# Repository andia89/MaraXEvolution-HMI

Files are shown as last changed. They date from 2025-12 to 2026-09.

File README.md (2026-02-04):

# MaraX Evolution - HMI

[](https://github.com/user-attachments/assets/6cd800d1-d086-4739-b1a8-fa24eb85fd67)

This repository contains the hardware designs, 3D printed parts, and firmware for the **MaraX Evolution Human-Machine Interface (HMI)**.

Designed to replace the standard LEDs and switches of the Lelit Mara X, this unit provides a rich touchscreen interface, real-time extraction charting, and a physical rotary encoder for tactile control. It communicates wirelessly with the [Main Controller](https://github.com/andia89/maraxevolution) via ESP-NOW, ensuring a low-latency, wire-free installation.

## Features

### Visual Interface

* **Real-Time Charting:** Live visualization of **Pressure (bar)** and **Flow Rate (g/s)** during the shot.

* **Live Telemetry:** Monitors Boiler Temp, HX Temp, Shot Timer, and Weight.

* **System Status:** Clear indicators for Heating, Ready, Steam Boost, and Error states.

### Control & Profiling

* **Profile Editor:** Built-in **Web Server** to create, edit, and save complex pressure/flow profiles graphically from your phone or PC.

* **Profile Management:** Store up to **32 custom profiles** on the device.

* **Manual Control:** "Fly-by-wire" manual mode using the rotary encoder to control pump pressure/flow in real-time.

* **Configuration:** Adjust PID targets, brew temperatures, and steam settings directly from the screen.

### Maintenance & Tools

* **Scale Calibration:** On-screen wizard to tare and calibrate the [MaraX Evolution Scale](https://github.com/andia89/maraxevolution-scale).

* **Cleaning Assistant:** Guided backflush/cleaning cycles with on-screen instructions.

* **Auto-Pairing:** Seamlessly pairs with the Main Controller via ESP-NOW protocol.

## Repository Structure

* `HMI/`: Nextion Editor source files (`.hmi`), compiled binaries (`.tft`), and asset generation scripts.

* `firmware/`: PlatformIO project for the HMI controller (ESP32).

* `hardware/`: STL files for the 3D printed housing and mounting brackets.

## Hardware Overview

The HMI consists of:

1. **Microcontroller:** Arduino Nano ESP32 (handling Logic, WiFi, Web Server).

2. **Display:** Nextion Edge Series (NX4848E028-011C).

3. **Input:** Rotary Encoder and Push Button (for precise adjustments).

4. **Housing:** Custom 3D printed enclosure.

## [User Guide](USERGUIDE.md)

## [Parts list](PARTS.md)

## [Assembly Instructions](ASSEMBLY.md)

## Firmware Installation

The firmware is built using **PlatformIO**.

1. Install [VSCode](https://code.visualstudio.com/) and the [PlatformIO extension](https://platformio.org/).
2. Open the `firmware` directory in PlatformIO.

### 1. Initial Flash (USB)
For the first installation, you must connect the ESP32 directly to your computer.
1. Connect the ESP32 via USB.
2. Select the default environment (`env:hmi`) in PlatformIO.
3. Click the **Upload** button (Right Arrow icon).

### 2. Subsequent Updates (OTA)
Once the HMI is installed in the machine and connected to your WiFi, you can update it wirelessly.
1. Ensure your computer and the HMI are on the same WiFi network.
2. Select the ota environment (`env:hmi-ota`) in PlatformIO.
3. Click **Upload**. PlatformIO will detect the network port and flash the device over the air.

## Firmware Configuration

The HMI firmware is designed to run on an **Arduino Nano ESP32**.

1. **WiFi Setup:** On first boot, the HMI will create a WiFi Access Point (AP) named `esp32-arduino-screen-Setup`. Connect to it to configure your home WiFi.

2. **Web Interface:** Once connected, access the Profile Editor at `http://esp32-arduino-screen.local` (or the device IP).

3. **Pairing:** The HMI automatically broadcasts an ESP-NOW pairing request. Ensure the Main Controller is powered on; they will find each other automatically.

## Licensing

This project is dual-licensed to protect the work while allowing for personal study and modification.

* **Firmware:** The source code located in the `/firmware` directory is licensed under the **PolyForm Noncommercial License 1.0.0**. You may modify and use it for personal projects, but **commercial use is prohibited**.

  * *Third-Party Libraries included:* Modified versions of [Nextion_X2](https://github.com/sstaub/NextionX2) (MIT).

* **Hardware:** The hardware designs, schematics, and 3D models located in the `/HMI` and `/hardware` directories are licensed under the **Creative Commons Attribution-NonCommercial 4.0 International (CC BY-NC 4.0)** license.

Please see the [LICENSE](LICENSE) file for the full legal text.

*Part of the [MaraX Evolution Ecosystem](https://github.com/andia89/maraxevolution).*

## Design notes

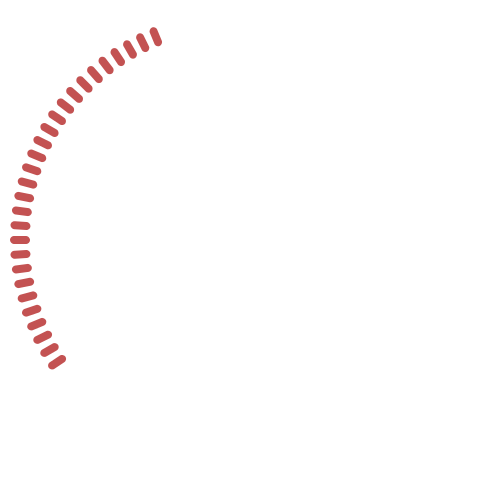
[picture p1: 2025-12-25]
HMI/pictures/boiler_28.png

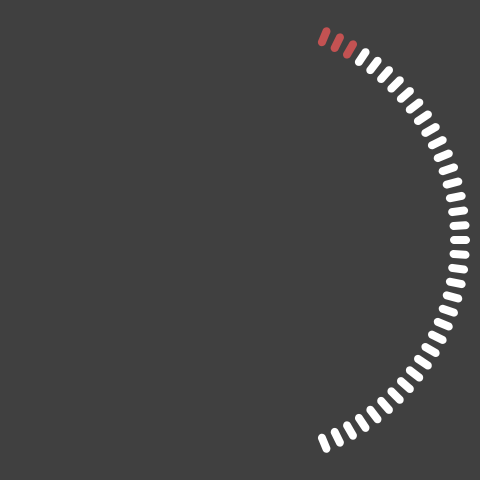
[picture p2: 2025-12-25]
HMI/pictures/brew_3.png

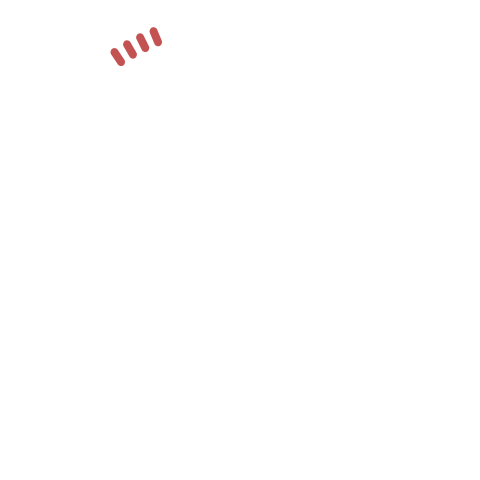
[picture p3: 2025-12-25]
HMI/pictures/boiler_4.png

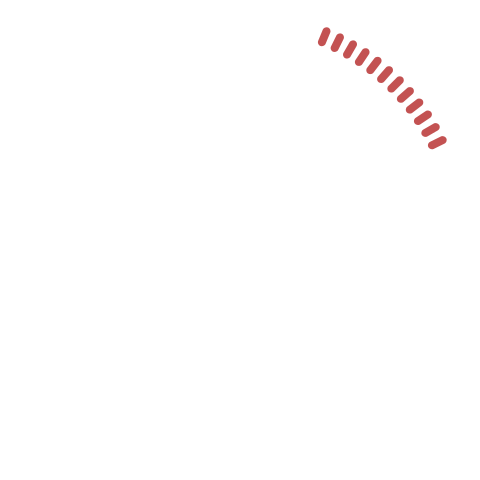
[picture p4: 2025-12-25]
HMI/pictures/brew_12.png

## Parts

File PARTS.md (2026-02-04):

# MaraX Evolution HMI - Parts List

This document lists all the components required to build the MaraX Evolution Human-Machine Interface (HMI).

## Electronics & Display

| Component | Description | Quantity | Notes |
| :--- | :--- | :---: | :--- |
| **Microcontroller** | Arduino Nano ESP32 | 1 | Must include headers. Installs into the bottom section of the housing. |
| **Display** | Nextion [NX4848E028-011C](https://nextion.tech/) | 1 | 2.8" Edge Series HMI Touchscreen. |
| **Rotary Encoder** | Bourns PEC16-4125F-N0012 | 1 | Used for manual pressure control and menu navigation. |
| **Tactile Switch** | 506-FSM5JH | 1 | External push button for the encoder assembly (if not integrated). |
| **Cabling** | Dupont Cables (F-F / M-F) | Set | For connecting the Arduino to the Display and Encoder. |
| **Storage** | Micro SD Card | 1 | Required only for flashing the firmware onto the Nextion screen. |

## Housing & Hardware

| Component | Description | Quantity | Notes |
| :--- | :--- | :---: | :--- |
| **3D Printed Parts** | Custom Enclosure | 1 Set | STL files are located in `HMI/3DParts/`. I printed mine in PLA and was quite happy with it|
| **Threaded Inserts** | [M3 Threaded Inserts](https://www.ruthex.de/en/products/ruthex-gewindeeinsatz-m3-100-stuck-rx-m3x5-7-messing-gewindebuchsen) | 10 | Standard heat-set inserts (e.g., Ruthex M3x5.7). Any should do|
| **Teflon Plunger** | [M3 Teflon Plunger](https://de.aliexpress.com/item/1005009562484175.html) | 3 | **Critical:** Get the longest version available. Used to provide smooth rotation feel. |
| **Friction Tape** | [Teflon Tape (10mm)](https://de.aliexpress.com/item/1005005280321356.html) | 1 Roll | Applied between moving 3D printed parts to remove friction. |
| **Fasteners** | M3 Machine Screws | Assorted | A selection of lengths (6mm - 12mm) for assembling the case. |

---

*Note: Links provided are for reference and may change over time.*

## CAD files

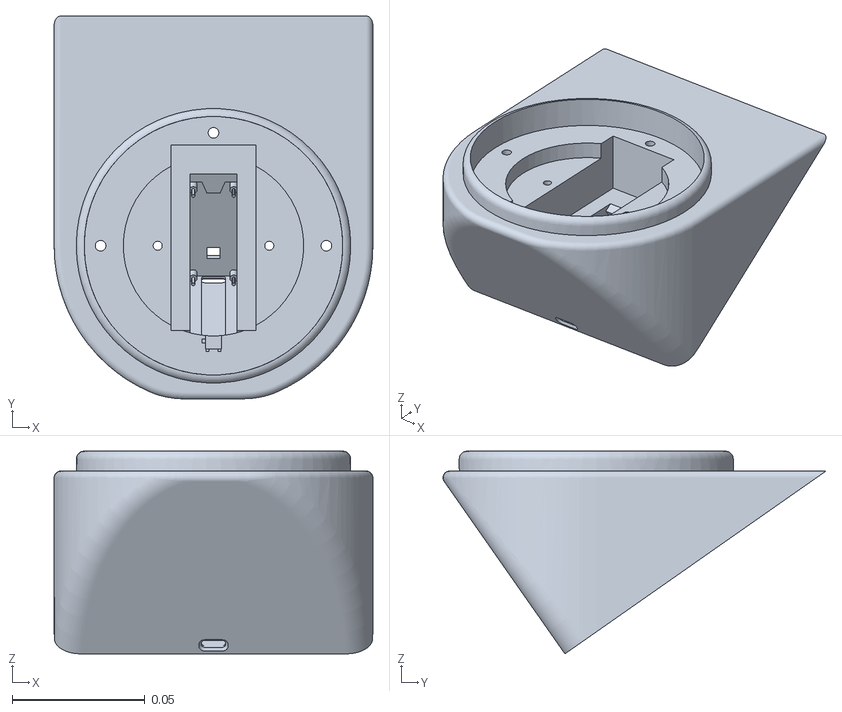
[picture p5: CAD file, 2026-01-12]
HMI/3DParts/Stand.stl
0.12 x 0.144 x 0.0763

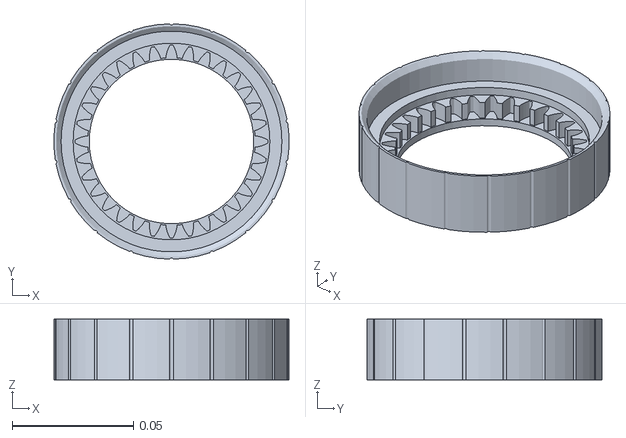
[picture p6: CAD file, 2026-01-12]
HMI/3DParts/Outer Housing.stl
0.0968 x 0.0969 x 0.025

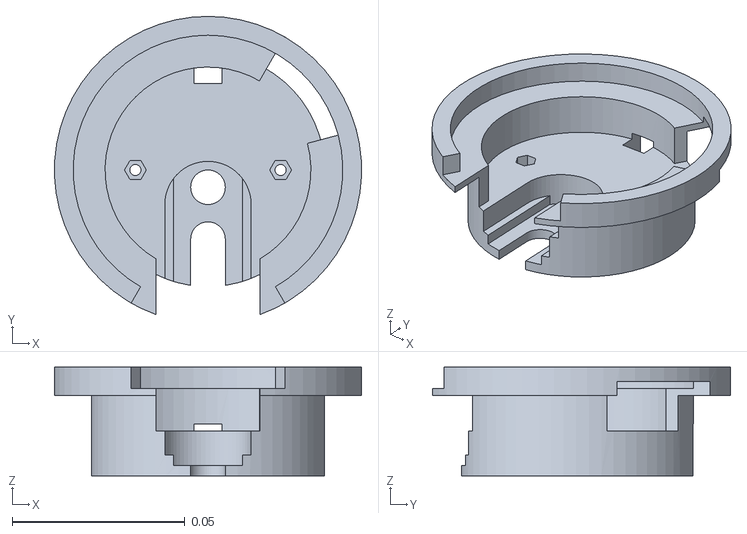
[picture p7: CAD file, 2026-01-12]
HMI/3DParts/Housing.stl
0.0888 x 0.0863 x 0.0314

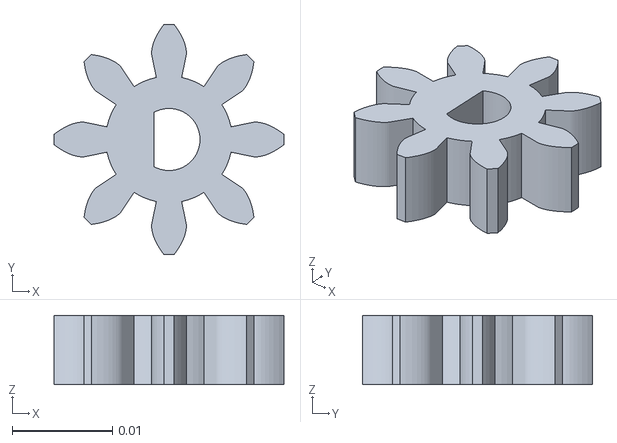
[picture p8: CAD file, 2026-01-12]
HMI/3DParts/Inner gear.stl
0.023 x 0.023 x 0.0069

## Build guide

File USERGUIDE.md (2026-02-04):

# **MaraX Evolution HMI \- User Guide**

This guide explains how to use the Nextion Touchscreen Interface and the Rotary Encoder to control your MaraX Evolution machine.

## **1\. First-Time Setup**

### **WiFi Configuration**

When powered on for the first time (or if it cannot connect to WiFi), the HMI creates a Hotspot.

1. Connect your phone or laptop to the WiFi network named: **esp32-arduino-screen-Setup**.  
2. A captive portal should open automatically (or visit 192.168.4.1).  
3. Select your home WiFi network and enter the password.  
4. The device will reboot and connect to your local network.

### **Pairing with Main Controller**

The HMI communicates with the machine via **ESP-NOW** (a fast, direct wireless protocol).

1. Ensure the **Main Controller** (inside the machine) is powered on.  
2. Power on the **HMI**.  
3. They will automatically find each other and pair within 10 seconds. You will see live temperature data appear once paired.

## **2\. Dashboard (Home Screen)**

This is the main view while brewing.

* **Live Chart:** Visualizes the shot in real-time.  
  * **Red Line:** Pressure (0-15 bar).  
  * **Blue Line:** Flow Rate (0-5 g/s) \[Requires Scale\].  
  * **White Line:** Target Profile.  
* **Data Fields:**  
  * **Timer:** Starts automatically when the pump engages.  
  * **Weight:** Live gram reading from the drip tray scale.  
  * **Temperatures:** Boiler (Steam) and Heat Exchanger (Brew) temps.  
* **Tare Button:** Zeros the scale manually \[Requires Scale\].

## **3\. Brewing Settings (Page 1\)**

Access this page to change machine parameters.

* **Brew Temperature:**  
  * Use the **Slider** on the touchscreen OR turn the **Rotary Encoder** to adjust the target brew temperature (e.g., 93.0°C).  
* **Brew Mode:**  
  * **Coffee Priority:** Keeps the heat exchanger at the perfect brew temp. Steam might be weaker.  
  * **Steam Priority:** Keeps the boiler hot for powerful steam. Brew temp may fluctuate more.  
* **Steam Boost:**  
  * When enabled, the machine aggressively heats the boiler immediately after a shot is finished to recover steam pressure quickly.

## **4\. Pressure & Flow Profiling (Page 2\)**

This menu controls how the pump operates during a shot.

### **Modes**

1. **Manual:** The machine behaves like a standard espresso machine (full pump power).  
2. **Flat:** The pump targets a specific constant value (e.g., maintain exactly 9.0 bar or 2.0 g/s).  
   * Select "Flat" and turn the encoder to set the target value.  
3. **Profile:** The machine follows a saved pre-programmed curve.

### **Profile Configuration**

* **Source:** Choose what the pump controls.  
  * **Pressure:** Standard profiling (e.g., pre-infusion at 2 bar, ramp to 9 bar).  
  * **Flow:** \[Requires Scale\] The pump adjusts to maintain a specific flow rate (e.g., 2.5 g/s) regardless of puck resistance.  
* **Target:** Choose when to advance to the next step.  
  * **Time:** Steps change after X seconds.  
  * **Weight:** Steps change after X grams are in the cup.

### **Selecting & Editing Profiles**

* **Select:** Turn the Rotary Encoder to cycle through saved profiles (displayed at the bottom).  
* **Edit (On-Screen):** Tap the table cells to select them, then turn the Encoder to adjust values (Target / Duration).  
* **Edit (Web Interface):** See Section 6 below.

## **5\. Maintenance (Page 3\)**

### **Scale Calibration**

1. Navigate to **System Settings**.  
2. Tap **Calibrate Scale**.  
3. **Step 1:** Ensure the scale is empty. Tap "Next" or the Encoder button to Tare.  
4. **Step 2:** Place a known weight on the scale.  
5. **Step 3:** Use the **Rotary Encoder** to adjust the displayed "Reference Weight" until it matches your known weight (e.g., 100.0g).  
6. Press the Encoder button to save.

### **Cleaning Cycle**

Automated backflush routine.

1. Insert a blind basket and detergent.  
2. Tap **Cleaning Cycle**.  
3. Follow the on-screen prompts:  
   * "Pull Lever" (Starts Pump)  
   * "Lower Lever" (When buzzing/pausing)  
   * Repeat 5x with detergent, 5x with water.

### **MQTT Configuration**

If connected to WiFi, tapping **System Settings** displays an IP address. Enter this IP in a web browser to configure your MQTT Broker settings for Home Assistant integration. This sets the MQTT settings for the main controller.

## **6\. Web Profile Editor**

The HMI hosts a built-in website for easier profile creation.

1. Ensure the HMI is connected to your WiFi.  
2. On a computer or phone connected to the same WiFi, open a browser.  
3. Go to: **http://esp32-arduino-screen.local**  
4. **Features:**  
   * Visual Graph Editor: Drag and drop points to create profiles.  
   * Save/Load: Save profiles to the HMI's memory slots (up to 32).  
   * Import/Export: Share profiles as JSON files.  
   * Live Sync: Changes made on the web update the screen instantly.

## **7\. Troubleshooting**

* **"System Message: Timeout"**: The main controller didn't respond. Ensure the machine is on. If the issue persists, reboot the HMI.  
* **No Chart Data:** Check if the scale is connected properly to the main controller.  
* **WiFi Issues:** If you change your WiFi password, the device will eventually reset to Hotspot mode (esp32-arduino-screen-Setup) so you can re-configure it.

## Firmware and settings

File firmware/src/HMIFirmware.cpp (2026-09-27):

// =================================================================
// --- LIBRARIES ---
// =================================================================
#include <WiFi.h>
#include "NextionTftUpdate.h"
#include <freertos/FreeRTOS.h>
#include <freertos/queue.h>
#include <ESP32RotaryEncoder.h>
#include "NextionX2.h"
#include <ArduinoOTA.h>
#include <ArduinoJson.h>
#include <esp_now.h>
#include <WebServer.h>
#include <DNSServer.h>
#include <WiFiManager.h>
#include <ESPmDNS.h>
#include <esp_pm.h>
#include <esp_wifi.h>
#include <esp_wifi_types.h>

// =================================================================
// --- CONFIGURATION & DEFINES ---
// =================================================================
bool SIMULATION_MODE = false;
const bool OFFLINE_MODE = false;
const float TEMP_SETPOINT_SCALE = 10.0f;
const int SHOT_RETENTION_TIME_MS = 10000;
const int CHART_RETENTION_TIME_MS = 3000;

// =================================================================
// --- HARDWARE PIN DEFINITIONS ---
// =================================================================
const uint8_t BUTTON_PIN = D5;
const uint8_t ENCODER_PIN_A = D4;
const uint8_t ENCODER_PIN_B = D3;
const uint8_t SERIAL_RX = D9;
const uint8_t SERIAL_TX = D8;

// =================================================================
// --- NETWORK CONFIGURATION ---
// =================================================================
// --- Wi-Fi Credentials ---
const char *WIFI_SSID = "";
const char *WIFI_PASSWORD = "";

// --- OTA (Over-the-Air Updates) ---
const char *OTA_HOSTNAME = "esp32-arduino-screen";
const char *OTA_PASSWORD = "1234";

// Nextion TFT updates: Python connects here even when the normal portal is off.
// Set a separate shared token if desired; the default reuses your OTA password.
const char *TFT_UPDATE_TOKEN = OTA_PASSWORD;
const uint16_t TFT_UPDATE_PORT = 8080;
NextionTftUpdate tftUpdater(Serial1, TFT_UPDATE_TOKEN, TFT_UPDATE_PORT);

// Received bools for settings
bool brewModeReceived = false;
bool steamBoostReceived = false; // Flag to know if false is real or default
bool flatValueReceived = false;
bool profilingSourceReceived = false;
bool profilingTargetReceived = false;
bool profilingModeReceived = false;
bool currentProfileReceived = false;
bool tempsetReceived = false;
bool setupFinished = false;

// --- Temporary Buffers for Web Forms ---
char form_mqtt_server[40] = ""; // Default values for the form
char form_mqtt_port_str[6] = "1883";
char form_mqtt_user[33] = "";
char form_mqtt_password[33] = "";

// --- WebServer for Connected Config ---
WebServer server(80);
bool portalRunning = false;
bool mqttSettingsPending = false;

// --- MQTT Topics ---
const char *mqtt_topic_state = "state";
const char *mqtt_topic_boiler_temp = "boiler_temp";
const char *mqtt_topic_hx_temp = "hx_temp";
const char *mqtt_topic_pressure = "pressure";
const char *mqtt_topic_heater = "heater";
const char *mqtt_topic_pump = "pump";
const char *mqtt_topic_brew_mode = "brew_mode";
const char *mqtt_topic_lever = "lever";
const char *mqtt_topic_setpoint = "tempsetbrew";
const char *mqtt_topic_weight = "weight";
const char *mqtt_topic_flow_rate = "flow_rate";
const char *mqtt_topic_steam_boost_status = "steam_boost";
const char *mqtt_topic_set_profiling_mode = "profiling_mode";
const char *mqtt_topic_set_profiling_source = "profiling_source";
const char *mqtt_topic_set_profiling_target = "profiling_target";
const char *mqtt_topic_set_profiling_flat = "profiling_flat_value";
const char *mqtt_topic_mqtt_server = "mqtt_server";
const char *mqtt_topic_mqtt_port = "mqtt_port";
const char *mqtt_topic_mqtt_user = "mqtt_user";
const char *mqtt_topic_mqtt_pass = "mqtt_pass";
const char *mqtt_topic_import_profile = "profile_data";
const char *mqtt_topic_active_profile_id = "active_profile_id";
// =================================================================
// --- SYSTEM & LIBRARY OBJECTS ---
// =================================================================
// --- Hardware ---
RotaryEncoder rotaryEncoder(ENCODER_PIN_A, ENCODER_PIN_B, BUTTON_PIN);
const long ROTARY_MIN_BOUND = 0;
const long ROTARY_MAX_BOUND = 12;

// --- Nextion Display Communication Port ---
// This gate lets the rest of the HMI resume after a failed flash without
// accidentally feeding ordinary UI commands into an unfinished TFT transfer.
// NextionX2 accepts a Stream-compatible object; the uploader uses raw Serial1.
class HmiDisplaySerial : public Stream
{
public:
  bool enabled = true;
  void begin(uint32_t baud) { Serial1.begin(baud, SERIAL_8N1, SERIAL_RX, SERIAL_TX); }
  int available() override { return enabled ? Serial1.available() : 0; }
  int read() override { return enabled ? Serial1.read() : -1; }
  int peek() override { return enabled ? Serial1.peek() : -1; }
  void flush() override
  {
    if (enabled)
      Serial1.flush(true);
  }
  size_t write(uint8_t value) override { return enabled ? Serial1.write(value) : 1; }
  size_t write(const uint8_t *data, size_t size) override
  {
    return enabled ? Serial1.write(data, size) : size;
  }
  using Print::write;
};
HmiDisplaySerial hmiDisplaySerial;
NextionComPort nextion;

// --- ESP-NOW Auto-Pairing ---
#define PAIR_REQUEST 1
#define PAIR_RESPONSE 2
char espNowMessageBuffer[250] = "";
uint8_t broadcastAddress[] = {0xFF, 0xFF, 0xFF, 0xFF, 0xFF, 0xFF};
uint8_t mainControllerMac[6] = {0x00, 0x00, 0x00, 0x00, 0x00, 0x00};
int myChannel = 0;
esp_now_peer_info_t peerInfo;
volatile bool espNowBusy = false;

// Define a structure for ESP-NOW messages
typedef struct struct_message
{
  char payload[250];
} struct_message;
typedef struct struct_pairing
{
  uint8_t id;
  uint8_t macAddr[6];
  uint8_t channel;
  char identifier[10];
} struct_pairing;
const char *espIdentifier = "espresso";

// The Wi-Fi callback must never use NextionX2 or touch Serial1. Queue packets
// for loop(), which owns all display traffic, including TFT upload traffic.
struct HmiRxPacket
{
  uint8_t mac[6];
  uint16_t len;
  uint8_t data[sizeof(struct_message)];
};
QueueHandle_t hmiRxQueue = nullptr;

struct_message myData;
struct_pairing pairingData;
// =================================================================
// --- GLOBAL STATE & CONTROL VARIABLES ---
// =================================================================
// --- Machine State (from MQTT) ---
float boilerTemp = 0.0f;
float brewTempSetPoint = 0.0f;
float hxTemp = 0.0f;
float pressure = 0.0f;
float weight = 0.0f;
bool isHeaterOn = false;
bool brewLeverLifted = false;
volatile bool pumpIsOn = false;
char machineState[64] = "";
char profilingMode[20] = "";
char profilingSource[20] = "pressure";
char profilingTarget[20] = "time";
unsigned long calibrationRequestTime = 0;
const long CALIBRATION_REQUEST_TIMEOUT_MS = 10000; // 10-second timeout
int calibrationStep = 0;                           // 0=Off, 1=Waiting for Tare, 2=Waiting for Weigh
unsigned long systemMessageClearTime = 0;
bool cleaningCycleActive = false;
unsigned long cleaningRequestTime = 0;
const long CLEANING_REQUEST_TIMEOUT_MS = 10000;
int cleaningCycleCount = 0;
float referenceWeight;
unsigned long chartStopTime = 0;

// --- ESP Now paring variables ---
unsigned long lastPairingRequestTime = 0;
const long PAIRING_REQUEST_INTERVAL_MS = 10000;
bool isPaired = false;
unsigned long lastControllerMessageTime = 0;
const long CONTROLLER_TIMEOUT_MS = 10000;

// --- Display & UI State ---
volatile int currentPage = 0;
int lastPageForSelection = 0;
volatile int currentSelectionIndex = 0;
volatile bool isItemSelected = false;

// --- Input Handling (Encoder & Button) ---
volatile long lastEncoderValue = 0;
volatile long encoderTicks = 0;
volatile bool buttonPressed = false;
portMUX_TYPE encoderMux = portMUX_INITIALIZER_UNLOCKED;
unsigned long lastEncoderActivityTime = 0;
int pendingSettingIndex = -1;
const int SETTING_ID_FLAT_VALUE = 100;
const int SETTING_ID_PROFILING_VALUE = 101;
const long PUBLISH_TIMEOUT = 1000;

// --- Shot & Flow Tracking ---
int shotTime = 0;
unsigned long shotStartTimeMillis = 0;
const int SHOT_START_THRESHOLD_S = 1;
bool shotIsActive = false;
const int MAX_SHOT_TIME_S = 50;

// --- Flow Rate Calculation ---
float flowRate = 0.0f;

// --- Raw Debug Data (for plotdebug mode) ---
float rawWeight = 0.0f;
float filteredWeight = 0.0f;
float filteredFlow = 0.0f;
unsigned long lastDebugDataTime = 0;
const long DEBUG_PLOT_TIMEOUT_MS = 2000;

// --- New scales for the debug plot mode ---
const float DEBUG_WEIGHT_MAX = 200.0;
const float DEBUG_WEIGHT_MIN = 0.0;
const float DEBUG_FLOW_MAX = 10.0;
const float DEBUG_FLOW_MIN = 0.0;

// --- Value Caching for Display Optimization ---
int lastShotTime_sent = -1;
float lastHxTemp_sent = -1.0f;
float lastBoilerTemp_sent = -1.0f;
float lastPressure_sent = -1.0f;
float lastTempSetpoint_sent = 0.0f;
float lastWeight_sent = -1.0f;
char lastMachineState_sent[64] = "";

// --- Settings Request Timer ---
unsigned long lastSettingsRequestTime = 0;
const long SETTINGS_REQUEST_INTERVAL_MS = 10000;

struct ProfileStep
{
  float target;
  float control;
};

struct EspressoProfile
{
  char name[65];
  bool isStepped;
  bool isTargetWeight;  // false = time, true = weight
  bool isSourceFlow;    // false = pressure, true = flow
  int8_t nextProfileId; // Profile ID to run next (-1 for none)
  int numSteps;
  ProfileStep steps[128];
};

EspressoProfile *currentProfile = nullptr;
#define MAX_PROFILES 16
EspressoProfile profiles[MAX_PROFILES];
int currentProfileIndex = 0;

EspressoProfile *executingProfile = nullptr;
unsigned long profileStartTime = 0;
float profileStartWeight = 0.0f;
int currentProfileStepIndex = 0;
float currentStepStartX = 0.0f;
float prevStepTargetY = 0.0f;

bool currentProfileDirty = false;
unsigned long profileIndexSettleTime = 0;
bool profileIndexPendingSave = false;
const unsigned long PROFILE_SAVE_DELAY_MS = 3000;

// Webserver
bool profileWebserverRunning = false;
extern const uint8_t profile_editor_start[] asm("_binary_src_www_profile_html_start");
extern const uint8_t profile_editor_end[] asm("_binary_src_www_profile_html_end");

// =================================================================
// --- NEXTION COMPONENT DEFINITIONS ---
// =================================================================
struct SliderBounds
{
  int min = 0;
  int max = 0;
};
// --- Page 0 (Main Brewing Screen) ---
NextionComponent t_shotTime(nextion, 0, 13);
NextionComponent t_weight(nextion, 0, 15);
NextionComponent t_machineState(nextion, 0, 14);
int waveformID = 12;
NextionComponent wf_pressure(nextion, 0, waveformID);
NextionComponent btn_tare(nextion, 0, 16);
NextionComponent va_highlight(nextion, 0, 45);
NextionComponent va_brewTemp(nextion, 0, 46);
NextionComponent va_boilerTemp(nextion, 0, 47);
NextionComponent va_setTemp(nextion, 0, 48);

// --- Page 1 (Main Settings) ---
NextionComponent slider_brewTemp(nextion, 1, 23);
NextionComponent l_brewTemp(nextion, 1, 20);
NextionComponent l_brewMode(nextion, 1, 21);
NextionComponent l_steamBoost(nextion, 1, 22);
NextionComponent btn_brewModeCoffee(nextion, 1, 26);
NextionComponent btn_brewModeSteam(nextion, 1, 27);
NextionComponent btn_steamBoost(nextion, 1, 28);
NextionComponent x_brewTemp(nextion, 1, 24);

// --- Page 2 (Profiling Settings) ---
NextionComponent btn_ModeManual(nextion, 2, 35);
NextionComponent btn_ModeFlat(nextion, 2, 36);
NextionComponent btn_ModeProfile(nextion, 2, 37);
NextionComponent btn_SourcePressure(nextion, 2, 38);
NextionComponent btn_SourceFlow(nextion, 2, 39);
NextionComponent btn_TargetTime(nextion, 2, 40);
NextionComponent btn_TargetWeight(nextion, 2, 41);
NextionComponent slt_Values(nextion, 2, 34);
NextionComponent t_profile(nextion, 2, 47);
NextionComponent sel_mode(nextion, 2, 33);
NextionComponent var_row(nextion, 2, 23);
NextionComponent var_col(nextion, 2, 24);
NextionComponent var_sel(nextion, 2, 43);
NextionComponent slt_flat(nextion, 2, 42);

// --- Page 3 (System settings) ---
NextionComponent t_systemMessage(nextion, 3, 20);
NextionComponent btn_systemSettings(nextion, 3, 21);
NextionComponent btn_cleaningCycle(nextion, 3, 22);
NextionComponent btn_calibrateScale(nextion, 3, 23);
int referenceWeightID = 24;
NextionComponent x_referenceWeight(nextion, 3, referenceWeightID);
int referenceWeightUnitID = 25;
NextionComponent t_referenceWeightUnit(nextion, 3, referenceWeightUnitID);

// =================================================================
// --- NEXTION UI LAYOUT & MAPPINGS ---
// =================================================================
const int HIGHLIGHT_COLOR = 65519;
const int NUM_PAGE1_COMPONENTS = 3;
NextionComponent *page1_components[NUM_PAGE1_COMPONENTS][4] = {
    {&l_brewTemp, &slider_brewTemp, nullptr, &x_brewTemp},
    {&l_brewMode, &btn_brewModeCoffee, &btn_brewModeSteam, nullptr},
    {&l_steamBoost, &slider_brewTemp, nullptr, nullptr}};
SliderBounds page1_bounds[NUM_PAGE1_COMPONENTS];
int page1_cachedValues[NUM_PAGE1_COMPONENTS];

char valueString[1024];
char profilingName[128];
float flatValue;
bool isProfilingStepped;
uint16_t selectedItemPage2 = 1025;
uint8_t rowPage2 = 0;
uint8_t columnPage2 = 2;
int sltHeight = 0;

// =================================================================
// --- CHART & PLOTTING CONFIGURATION ---
// =================================================================
float const PRESSURE_MAX = 15;
float const PRESSURE_MIN = 0;
float const FLOW_RATE_MAX = 5.0;
float const FLOW_RATE_MIN = 0.0;

int chartWidth = 0;
int chartHeight = 0;
int plotPointsAdded = 0;

// =================================================================
// --- FORWARD DECLARATIONS ---
// =================================================================
// --- Setup & Core Loop ---
void setup();
void loop();

// --- Network & MQTT Functions ---
void setup_wifi();
void OnDataRecv(const uint8_t *mac_addr, const uint8_t *incomingData, int len);
void OnDataSent(const uint8_t *mac_addr, esp_now_send_status_t status);
void processReceivedPacket(const uint8_t *mac_addr, const uint8_t *incomingData, int len);
void processReceivedPackets(bool discard);
const char *canStartTftUpdate();
void resumeAfterTftUpdate(bool displayReady);
void publishData(const char *key, const char *value, bool esNowSendNow = true);
bool parseBool(const char *value);
void handleIncomingMessage(char *message);
void publishSetting();
void checkEncoderPublish();
void sendEspNowBuffer();
void sendPendingMqttSettings();
void resetPairing();
void manageSettingsRequests();
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
void loop()
{
  // Serialize all Nextion access in this task. During flashing, discard live
  // ESP-NOW telemetry; request a fresh settings snapshot when the upload ends.
  processReceivedPackets(tftUpdater.busy());
  if (!OFFLINE_MODE)
  {
    tftUpdater.handle();
  }
  bool displayReady;
  if (tftUpdater.takeFinished(displayReady))
  {
    resumeAfterTftUpdate(displayReady);
  }
  if (tftUpdater.busy())
  {
    hmiDisplaySerial.enabled = false;
    // Do not run NextionX2, the normal portal, serial console commands, or
    // ArduinoOTA concurrently with the TFT transfer. Wi-Fi tasks still run.
    portENTER_CRITICAL(&encoderMux);
    encoderTicks = 0;
    buttonPressed = false;
    portEXIT_CRITICAL(&encoderMux);
    // Drop console input rather than execute stale commands after a flash.
    for (int i = 0; i < 256 && Serial.available(); ++i)
      Serial.read();
    delay(1);
    return;
  }
  if (Serial.available())
  {
    static char cmdBuffer[4096];
    size_t len = Serial.readBytesUntil('\n', cmdBuffer, sizeof(cmdBuffer) - 1);
    cmdBuffer[len] = '\0';

    if (len > 0 && cmdBuffer[len - 1] == '\r')
    {
      cmdBuffer[len - 1] = '\0';
      len--;
    }

    if (len > 0)
    {
      if (strcmp(cmdBuffer, "sim_on") == 0)
      {
        SIMULATION_MODE = true;
        pumpIsOn = true;                // "Turn on" the virtual pump
        brewLeverLifted = true;         // "Lift" the virtual lever
        shotStartTimeMillis = millis(); // Initialize the timer

        Serial.println(">>> Simulation Mode ENABLED & Shot STARTED");
      }
      else if (strcmp(cmdBuffer, "sim_off") == 0)
      {
        SIMULATION_MODE = false;
        pressure = 0;
        weight = 0;
        pumpIsOn = false;
        Serial.println(">>> Simulation Mode DISABLED");
      }
      else if (strncmp(cmdBuffer, "import_profile=", 15) == 0)
      {
        Serial.println("Serial command received: importing profile...");
        importProfileJson(cmdBuffer + 15);
      }
      else if (strncmp(cmdBuffer, "delete_profile=", 15) == 0)
      {
        int indexToDelete = atoi(cmdBuffer + 15);
        deleteProfile(indexToDelete);
      }
      else if (strncmp(cmdBuffer, "start_webserver", 15) == 0)
      {
        startProfilePortal();
      }
      else if (strncmp(cmdBuffer, "request", 7) == 0)
      {
        publishData("request", "settings", true);
      }
      else
      {
        Serial.print("Sending to Nextion: ");
        Serial.println(cmdBuffer);
        nextion.command(cmdBuffer);
      }
    }
  }

  if (profileIndexPendingSave && (millis() - profileIndexSettleTime > PROFILE_SAVE_DELAY_MS))
  {
    saveCurrentProfileIndex();
    profileIndexPendingSave = false;
    Serial.println("Settled: Saved new active profile index to NVS.");
  }

  if (hmiDisplaySerial.enabled && (chartWidth <= 0 || chartHeight <= 0))
  {
    Serial.println("Attempting to fetch chart dimensions...");
    chartWidth = wf_pressure.attributeValue("w");
    chartHeight = wf_pressure.attributeValue("h");
    if (chartWidth > 0)
    {
      Serial.printf("Chart dimensions fetched: W=%d, H=%d\n", chartWidth, chartHeight);
    }
    else
    {
      Serial.println("Failed to fetch chart dimensions yet...");
      chartWidth = 0;
      chartHeight = 0;
    }
  }
  if (!OFFLINE_MODE)
  {
    ArduinoOTA.handle();
    if (portalRunning || profileWebserverRunning)
    {
      server.handleClient();
    }
  }

  if (systemMessageClearTime > 0 && millis() > systemMessageClearTime)
  {
    if (currentPage == 3)
    {
      t_systemMessage.text("");
    }
    systemMessageClearTime = 0;
  }

  if (calibrationRequestTime > 0 && (millis() - calibrationRequestTime > CALIBRATION_REQUEST_TIMEOUT_MS))
  {
    Serial.println("Calibration request timed out.");
    calibrationStep = 0;
    calibrationRequestTime = 0;

    if (currentPage == 3)
    {
      t_systemMessage.text("Calibration Failed:\r\nTimeout");
    }
    systemMessageClearTime = millis() + 5000;

    char cmdBuffer[10];
    sprintf(cmdBuffer, "vis %d,0", referenceWeightID);
    nextion.command(cmdBuffer);
    sprintf(cmdBuffer, "vis %d,0", referenceWeightUnitID);
    nextion.command(cmdBuffer);
  }

  if (cleaningRequestTime > 0 && (millis() - cleaningRequestTime > CLEANING_REQUEST_TIMEOUT_MS))
  {
    Serial.println("Cleaning request timed out.");
    cleaningRequestTime = 0;
    cleaningCycleActive = false;
    cleaningCycleCount = 0;

    if (currentPage == 3)
    {
      t_systemMessage.text("Cleaning Failed:\r\nTimeout");
    }
    systemMessageClearTime = millis() + 5000;
  }

  if (isPaired && (millis() - lastControllerMessageTime > CONTROLLER_TIMEOUT_MS))
  {
    resetPairing();
  }
  int newCurrentPage = nextion.getCurrentPageID();
  if (newCurrentPage != currentPage)
  {
    currentPage = newCurrentPage;
    cleanCurrentPage();
    lastHxTemp_sent = -1.0f;
    lastBoilerTemp_sent = -1.0f;
    lastPressure_sent = -1.0f;
    lastTempSetpoint_sent = -1.0f;
    lastWeight_sent = -1.0f;
    lastShotTime_sent = -1;
    strcpy(lastMachineState_sent, "");
  }
  if (newCurrentPage != 3 && portalRunning)
  {
    stopConfigurationPortal();
  }
  if (!OFFLINE_MODE && !isPaired && !SIMULATION_MODE)
  {
    if (millis() - lastPairingRequestTime > PAIRING_REQUEST_INTERVAL_MS)
    {
      Serial.println("Not paired. Retrying auto-pairing request...");

      pairingData.id = PAIR_REQUEST;
      pairingData.channel = myChannel;
      strcpy(pairingData.identifier, espIdentifier);
      WiFi.macAddress(pairingData.macAddr);

      esp_now_send(broadcastAddress, (uint8_t *)&pairingData, sizeof(pairingData));

      lastPairingRequestTime = millis();
    }
  }
  if (SIMULATION_MODE)
  {
    simulateShot();
  }
  if (!OFFLINE_MODE)
  {
    manageSettingsRequests();
  }

  nextion.update();
  if (hmiDisplaySerial.enabled)
  {
    handleEncoder();
    handleButton();
    checkEncoderPublish();
  }
  else
  {
    portENTER_CRITICAL(&encoderMux);
    encoderTicks = 0;
    buttonPressed = false;
    portEXIT_CRITICAL(&encoderMux);
  }
  shotTime = getShotTime(pumpIsOn);

  updateDisplay();
  updateChart();
  newCurrentPage = nextion.getCurrentPageID();
  if (newCurrentPage != currentPage)
  {
    currentPage = newCurrentPage;
  }
}

// --- Network & MQTT Functions ---
void setup_wifi()
{
  WiFi.mode(WIFI_STA);
  delay(100);

  WiFiManager wm;
  wm.setClass("invert");
  wm.setMinimumSignalQuality(30);
  wm.setConfigPortalTimeout(180);

  Serial.println("--- Wi-Fi Setup ---");
  Serial.println("Attempting to connect to saved Wi-Fi...");

  char apName[128];
  snprintf(apName, sizeof(apName), "%s-Setup", OTA_HOSTNAME);

  bool res = wm.autoConnect(apName);

  if (!res)
  {
    Serial.println("❌ FAILED to connect to Router (Timeout or wrong creds).");
  }
  else
  {
    Serial.println("✅ connected to Router!");
    Serial.print("   IP Address: ");
    Serial.println(WiFi.localIP());
    Serial.print("   Channel: ");
    Serial.println(WiFi.channel());
  }
  WiFi.setSleep(false);

  if (!MDNS.begin(OTA_HOSTNAME))
  {
    Serial.println("Error setting up MDNS responder!");
  }
  else
  {
    Serial.println("MDNS responder started: http://");
    Serial.print(OTA_HOSTNAME);
    Serial.println(".local");
    MDNS.addService("http", "tcp", 80);
  }
}
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

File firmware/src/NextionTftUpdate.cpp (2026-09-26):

#include "NextionTftUpdate.h"
#include <ctype.h>
#include <string.h>

namespace {
constexpr uint32_t HTTP_TIMEOUT_MS = 3000;
constexpr uint32_t NETWORK_IDLE_MS = 10000;
constexpr uint32_t ACK_TIMEOUT_MS = 5000;
constexpr uint32_t UART_IDLE_MS = 3000;
constexpr uint32_t PROBE_MS = 600;
constexpr uint32_t BOOT_TIMEOUT_MS = 60000;
constexpr uint32_t FAILURE_RECOVERY_MS = 12000;
// The original project uses 115200 at runtime and 9600 after a display restart.
// Also cover other baud rates a newly compiled TFT might select at boot.
constexpr uint32_t PROBE_BAUDS[] = {
  115200, 9600, 57600, 38400, 19200, 4800, 2400,
  230400, 250000, 256000, 512000, 921600
};
constexpr size_t PROBE_COUNT = sizeof(PROBE_BAUDS) / sizeof(PROBE_BAUDS[0]);
}

NextionTftUpdate::NextionTftUpdate(HardwareSerial &uart, const char *token,
                                 uint16_t port)
    : uart_(uart), token_(token), server_(port) {}

void NextionTftUpdate::begin(StartCheck startCheck) {
  startCheck_ = startCheck;
  const char *headers[] = {"X-Update-Token"};
  server_.collectHeaders(headers, 1);
  server_.on("/api/nextion/status", HTTP_GET, [this]() { handleStatus(); });
  server_.on("/api/nextion/update", HTTP_POST, [this]() { handleStart(); });
  server_.onNotFound([this]() { sendError(404, "Unknown update endpoint"); });
  server_.begin();
  started_ = true;
}

bool NextionTftUpdate::authenticate() {
  if (token_ == nullptr || token_[0] == '\0') {
    sendError(503, "Configure a nonempty TFT_UPDATE_TOKEN in the firmware");
    return false;
  }
  if (server_.header("X-Update-Token") != token_) {
    sendError(401, "Wrong X-Update-Token");
    return false;
  }
  return true;
}

void NextionTftUpdate::sendError(int code, const char *reason) {
  JsonDocument doc;
  doc["error"] = reason;
  String body;
  serializeJson(doc, body);
  server_.sendHeader("Cache-Control", "no-store");
  server_.send(code, "application/json", body);
}

bool NextionTftUpdate::validJobId(const String &id) {
  if (id.length() != 32) return false;
  for (size_t i = 0; i < id.length(); ++i)
    if (!isxdigit(static_cast<unsigned char>(id[i]))) return false;
  return true;
}

bool NextionTftUpdate::validUrl(const String &url) {
  // Numeric IPv4 avoids an unbounded external DNS lookup during an update.
  // The supplied Python server produces precisely this kind of URL.
  if (!url.startsWith("http://") || url.length() > 512) return false;
  for (size_t i = 0; i < url.length(); ++i)
    if (static_cast<unsigned char>(url[i]) <= 32 || url[i] == '#') return false;
  int slash = url.indexOf('/', 7);
  if (slash < 0) return false;
  String authority = url.substring(7, slash);
  int colon = authority.indexOf(':');
  String host = colon < 0 ? authority : authority.substring(0, colon);
  IPAddress ip;
  if (!ip.fromString(host)) return false;
  if (colon >= 0) {
    String port = authority.substring(colon + 1);
    if (port.length() == 0 || port.length() > 5) return false;
    for (size_t i = 0; i < port.length(); ++i)
      if (!isdigit(static_cast<unsigned char>(port[i]))) return false;
    if (port.toInt() < 1 || port.toInt() > 65535) return false;
  }
  return true;
}

void NextionTftUpdate::handleStart() {
  if (!authenticate()) return;
  if (!server_.hasArg("plain") || server_.arg("plain").length() > 1024) {
    sendError(400, "Expected a JSON body of at most 1024 bytes");
    return;
  }
  JsonDocument doc;
  if (deserializeJson(doc, server_.arg("plain"))) {
    sendError(400, "Invalid JSON");
    return;
  }
  String id = doc["job_id"] | "";
  String url = doc["url"] | "";
  if (!validJobId(id) || !validUrl(url) || !doc["size"].is<uint32_t>() ||
      !doc["timeout_s"].is<uint32_t>()) {
    sendError(400, "Require job_id (32 hex), numeric IPv4 HTTP URL, size and timeout_s");
    return;
  }
  uint32_t size = doc["size"].as<uint32_t>();
  uint32_t timeout = doc["timeout_s"].as<uint32_t>();
  if (size == 0 || size > MAX_FILE_SIZE || timeout < 30 ||
      timeout > MAX_TIMEOUT_SECONDS) {
    sendError(400, "Invalid size (1..128 MiB) or timeout_s (30..21600)");
    return;
  }
  // A retransmitted POST with the same identity NEVER flashes a second time.
  if (jobId_.length() && id == jobId_) {
    if (url != url_ || size != fileSize_ || timeout * 1000UL != timeoutMs_)
      sendError(409, "This job_id was already used for a different request");
    else
      sendStatus(busy() ? 202 : 200);
    return;
  }
  if (busy()) {
    sendError(409, "Another display update is in progress");
    return;
  }
  if (WiFi.status() != WL_CONNECTED) {
    sendError(503, "Wi-Fi is not connected");
    return;
  }
  if (startCheck_) {
    const char *reason = startCheck_();
    if (reason) {
      sendError(409, reason);
      return;
    }
  }
  jobId_ = id;
  url_ = url;
  fileSize_ = size;
  timeoutMs_ = timeout * 1000UL;
  acknowledged_ = sent_ = 0;
  blockSize_ = blockUsed_ = blockSent_ = 0;
  finished_ = uploadCommandSent_ = transferComplete_ = false;
  pendingResult_ = "";
  status_ = "running";
  message_ = "Update accepted";
  startedAt_ = phaseAt_ = millis();
  phase_ = Phase::Queued;
  sendStatus(202); // Respond first; do not run the upload inside this HTTP handler.
}

void NextionTftUpdate::handleStatus() {
  if (authenticate()) sendStatus(200);
}

void NextionTftUpdate::sendStatus(int code) {
  JsonDocument doc;
  doc["job_id"] = jobId_;
  doc["status"] = status_;
  doc["phase"] = phaseName();
  doc["message"] = message_;
  doc["busy"] = busy();
  doc["size"] = fileSize_;
  doc["sent"] = sent_;
  doc["acknowledged"] = acknowledged_;
  doc["display_ready"] = displayReady_;
  doc["baud"] = NORMAL_BAUD;
  doc["timeout_s"] = timeoutMs_ / 1000;
  String body;
  serializeJson(doc, body);
  server_.sendHeader("Cache-Control", "no-store");
  server_.send(code, "application/json", body);
}

bool NextionTftUpdate::busy() const { return phase_ != Phase::Idle; }

bool NextionTftUpdate::takeFinished(bool &ready) {
  if (!finished_) return false;
  finished_ = false;
  ready = displayReady_;
  return true;
}

bool NextionTftUpdate::recovering() const {
  return phase_ == Phase::RecoverDelay || phase_ == Phase::RecoverProbe ||
         phase_ == Phase::NormalizeDelay || phase_ == Phase::NormalizeWait;
}

const char *NextionTftUpdate::phaseName() const {
  switch (phase_) {
    case Phase::Idle: return "idle";
    case Phase::Queued: return "queued";
    case Phase::OpenHttp: return "connecting_http";
    case Phase::ReadBlock: return "reading_file";
    case Phase::Probe: return "finding_display";
    case Phase::WaitStart: return "waiting_for_upload_ready";
    case Phase::SendBlock: return "sending";
    case Phase::WaitAck: return "waiting_for_ack";
    default: return "reconnecting_display";
  }
}

void NextionTftUpdate::handle() {
  if (!started_) return;
  server_.handleClient();
  if (busy()) tick();
}
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

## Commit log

2025-12-25 Revise README for better structure and clarity
    Updated the README to improve clarity and organization, including sections on repository structure, assembly, installation, firmware compilation, and support.
2026-01-12 adds 3d parts
    [Housing.stl, Inner gear.stl, Outer Housing.stl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]
2026-09-26 allows flashiiing of HMI display via ESP32
